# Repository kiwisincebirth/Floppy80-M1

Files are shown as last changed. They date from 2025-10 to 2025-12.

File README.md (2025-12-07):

# Floppy 80 for the TRS-80 Model I

## Features

The Floppy-80 is a Hardware and software solution that emulates 
the following features of the Expansion Interface
- A Floppy Disc controller
  - supports 3 floppy drives
  - single and double-density
  - single and double-sided
  - up to 90 cylinders
  - DMK disk format supported
- 32k RAM expansion (optional)
- 40Hz RTC interrupt generation

Additionally, the following features are provided:
- A Hard Disk Controller (optional)
  - supports up to 2 hard drives
  - Uses same image format as FreHD
- Wait State Generation (optional)
- Software Debugging Interface

An SD card is required to store disk images and configuration data

## Hardware

The Floppy-80 consists of a board that connects to the Model-1 expansion edge connector.
The board contains an SD card socket to provide disk images and a
Raspberry Pi Pico 2 microcontroller which does the emulation

[Building and testing](HARDWARE.md) the board is covered separately.

## Software

The software provided includes 2 main components
* Firmware running on Raspberry Pi, that provides the emulation
* FDC Utility (TRS DOS, and CPM) running on TRS-80 for emulator control

See the separate [Software Build Guide](BUILDING.md) for details on 
building the Floppy-80 software

## User Guide

For User Instructions please see the separate [User Guide](USER-GUIDE.md)

## Credits

## Resources

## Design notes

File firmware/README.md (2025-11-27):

########################################################################

Floppy 80 for the TRS-80 Model I

The Floppy80-M1 emulates the following features of the Expansion Interface
- 32k RAM explansion
- Up to 3 floppy drives
  - 1 and 2 sided
  - single and double density
  - up to 90 cylinders
- Up to 2 hard drives

Configuration of the Floppy80-M1 is performed with the placement of
files on the SD-Card inserted in its card reader.
The files are as follows:

boot.cfg
- specified the defaul ini file to load at reset of the Floppy80
  when the floppy 80 boots or is reset it reads the contents of
  the boot.cfg to determine the default configuration ini file.

ini files
- specifies the disk images and options after reset.

  ini options
  - Drive0 - specified the image to load for drive :0
  - Drive1 - specified the image to load for drive :1
  - Drive2 - specified the image to load for drive :2
  - HD0 - specifies the image to load for tyhe first hard drive
  - HD1 - specifies the image to load for tyhe second hard drive
  - Doubler - 1 = doubler is enabled; 0 = doubler is disabled;

dmk files
- these are virtual disk images with a specific file format
  that allows them to be generated and used with a number
  of existing programs and simulators.

vitual hard drive images
- these are virtual hard drive images with a specific file format.
  They are used by the FreHD and TRS80-GP.

########################################################################

FDC utility
- Is a utility to interact with the Floppy80 from within the
  TRS-80 Model I operating environment.  Versions of FDC exist
  for the following operating systems

  - CPM 1.4.1 (Lifeboat)
  - CPM 1.5 (FMG)
  - Double DOS 4.2.4
  - DOS Plus 3.50
  - LDOS 5.3.1
  - MultiDOS 4.01
  - NEWDOS 3.0
  - NEWDOS 80 V2.0
  - TRSDOS 2.3
  - UltraDOS 4.2.0
  - VTDOS 3.0.0
  - VTDOS 4.0.1

  FDC.COM is used with the two CP/M OSs and
  FDC/CMD is used with the rest.

  Usage

  FDC OPT PARM1:drive

  Where:
  - OPT is one of the following
    - STA - returns the status of the Floppy80.
    - DIR - displays a list of file in the root folder of the SD-Card.
    - INI - switches between tyhe differnt ini file on the SD-Card.
    - DMK - allows the mounting of DMK disk images in the root folder
            of the SD-Card for a specified drive (0, 1 or 2).
    - FOR - copys a DMK disk image from the FOR folder of the SD-Card
            to one of the mounted disk images (0, 1 or 2).
    - IMP - imports a file from the root folder of the SD-Card
            into one of the mounted disk images (0, 1 or 2).

  FDC STA
  - Displays the contects to the ini file specified by boot.cfg

  FDC DIR filter
  - Displays a list of files in the root folder of the SD-Card.
    If filter is specified only files contain the filter character
    sequence are displayed.  If filter is not specified all files
    are displayed.

  FDC INI filename.exe
  - filename.exe is optional.  If not specified and list of ini files
    on the SD-Card will be displayed allow you to select the one to
    write to boot.cfg.  When specified FDC will bypass the file
    selection process.

  FDC DMK filename.exe n
  - filename.exe:n is optional.  When specified it will mount
    the dmk file names by filename.exe into the drive specified
    by n.  For example

    FDC DMK LDOS-DATA.DMK 2

    will mount the dmk file LDOS-DATA.DMK into drive :2

    If filename.exe:n is not specfied a list of dmk files
    will be listed allowing you to select on and the drive
    to mount it into.

  FDC FOR
  - list the files contained in the FMT folder of the SD-Card
    from which you can select one and specify the drive image
    to replace with it.  This is useful to generate blank disk
    images.

  FDC IMP filename.exe:n
  - imports the specified file from the root folder of the
    FAT32 formated SD-Card to the disk image indicated by n.

########################################################################

Building Source
- Floppy80 firmware
  - Uses VSCode and the Pi Pico extension.

- FDC TRS (utility for the TRSDOS related utility)
  
  - zmac fdc.asm
  - use TRS80GP to import FDC/CMD onto a disk image
    
    - trs80gp -m1 -vs -frehd -frehd_dir zout -turbo -mem 48 -d0 dmk\ld531-0.dmk -d1 dmk\ld531-1.dmk -i "IMPORT2 FDC.CMD FDC/CMD:1\r"

- FDC CP/M (utility for the CP/M related utility)
  1. Compile program into a hex file.
  
       zmac fdc.asm
     
  2. Run TRS80GP loading the CP/M disk images.
     
       start trs80gp -m1 -vs -frehd -frehd_dir zout -turbo -mem 48 -d0 CPM141-0.dmk -d1 CPM141-1.dmk -d2 CPM141-2.dmk
     
  3. Select Load from TRS80GP File menu and select the hex file.
  
  4. Run "SAVE 20 B:FDC.COM" to save program memory contents to a .com file.
     As the program grows you will need to increase the value after SAVE.

     SAVE n ufn cr
     
       n   - number of 256-byte pages to be saved.
     
       ufn - unambiguous file name.
     
       cr  - carriage return.

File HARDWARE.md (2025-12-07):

# Floppy 80 (Model I) Hardware

The main components Required are
* Printed Circuit Board
* Raspberry Pi Pico 2 microcontroller
* SN74LVCC4245ADWR Buffer Chips (4x)
* SD Card Socket (SMD)
* 40 pin PCB Edge Connector

## Bill of Materials

For a full Bill Of Materials please see

## Assembly Guide

## Programming Firmware

## Testing

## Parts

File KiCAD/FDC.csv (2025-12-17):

Reference | Qty | Value | Digikey | Cost | Place
C1,C2,C3,C4,C5,C6,C7,C8,C9 | 9 | 100nF | 732-8080-1-ND | 0.10
D1 | 1 | LED | 754-1519-1-ND | 0.70
D2 | 1 | PMEG4010CEJ |  | 0.28 | DNP
J2 | 1 | Conn_02x20_Odd_Even | A31723-ND | 3.69
J3 | 1 | SD_Card | 609-3956-1-ND | 2.13
Q1,Q2 | 2 | SSM3K324RLFCT-ND | SSM3K324RLFCT-ND | 0.37
R1 | 1 | 100 | RMCF0805FT100RCT-ND | 0.10
R2,R3,R4,R6,R8 | 5 | 1k | A106056CT-ND | 0.10
U1,U3,U4,U5 | 4 | SN74LVCC4245ADWR | 296-26634-1-ND | 1.83
U2 | 1 | Pico 2 | 2648-SC1631CT-ND | 5.00

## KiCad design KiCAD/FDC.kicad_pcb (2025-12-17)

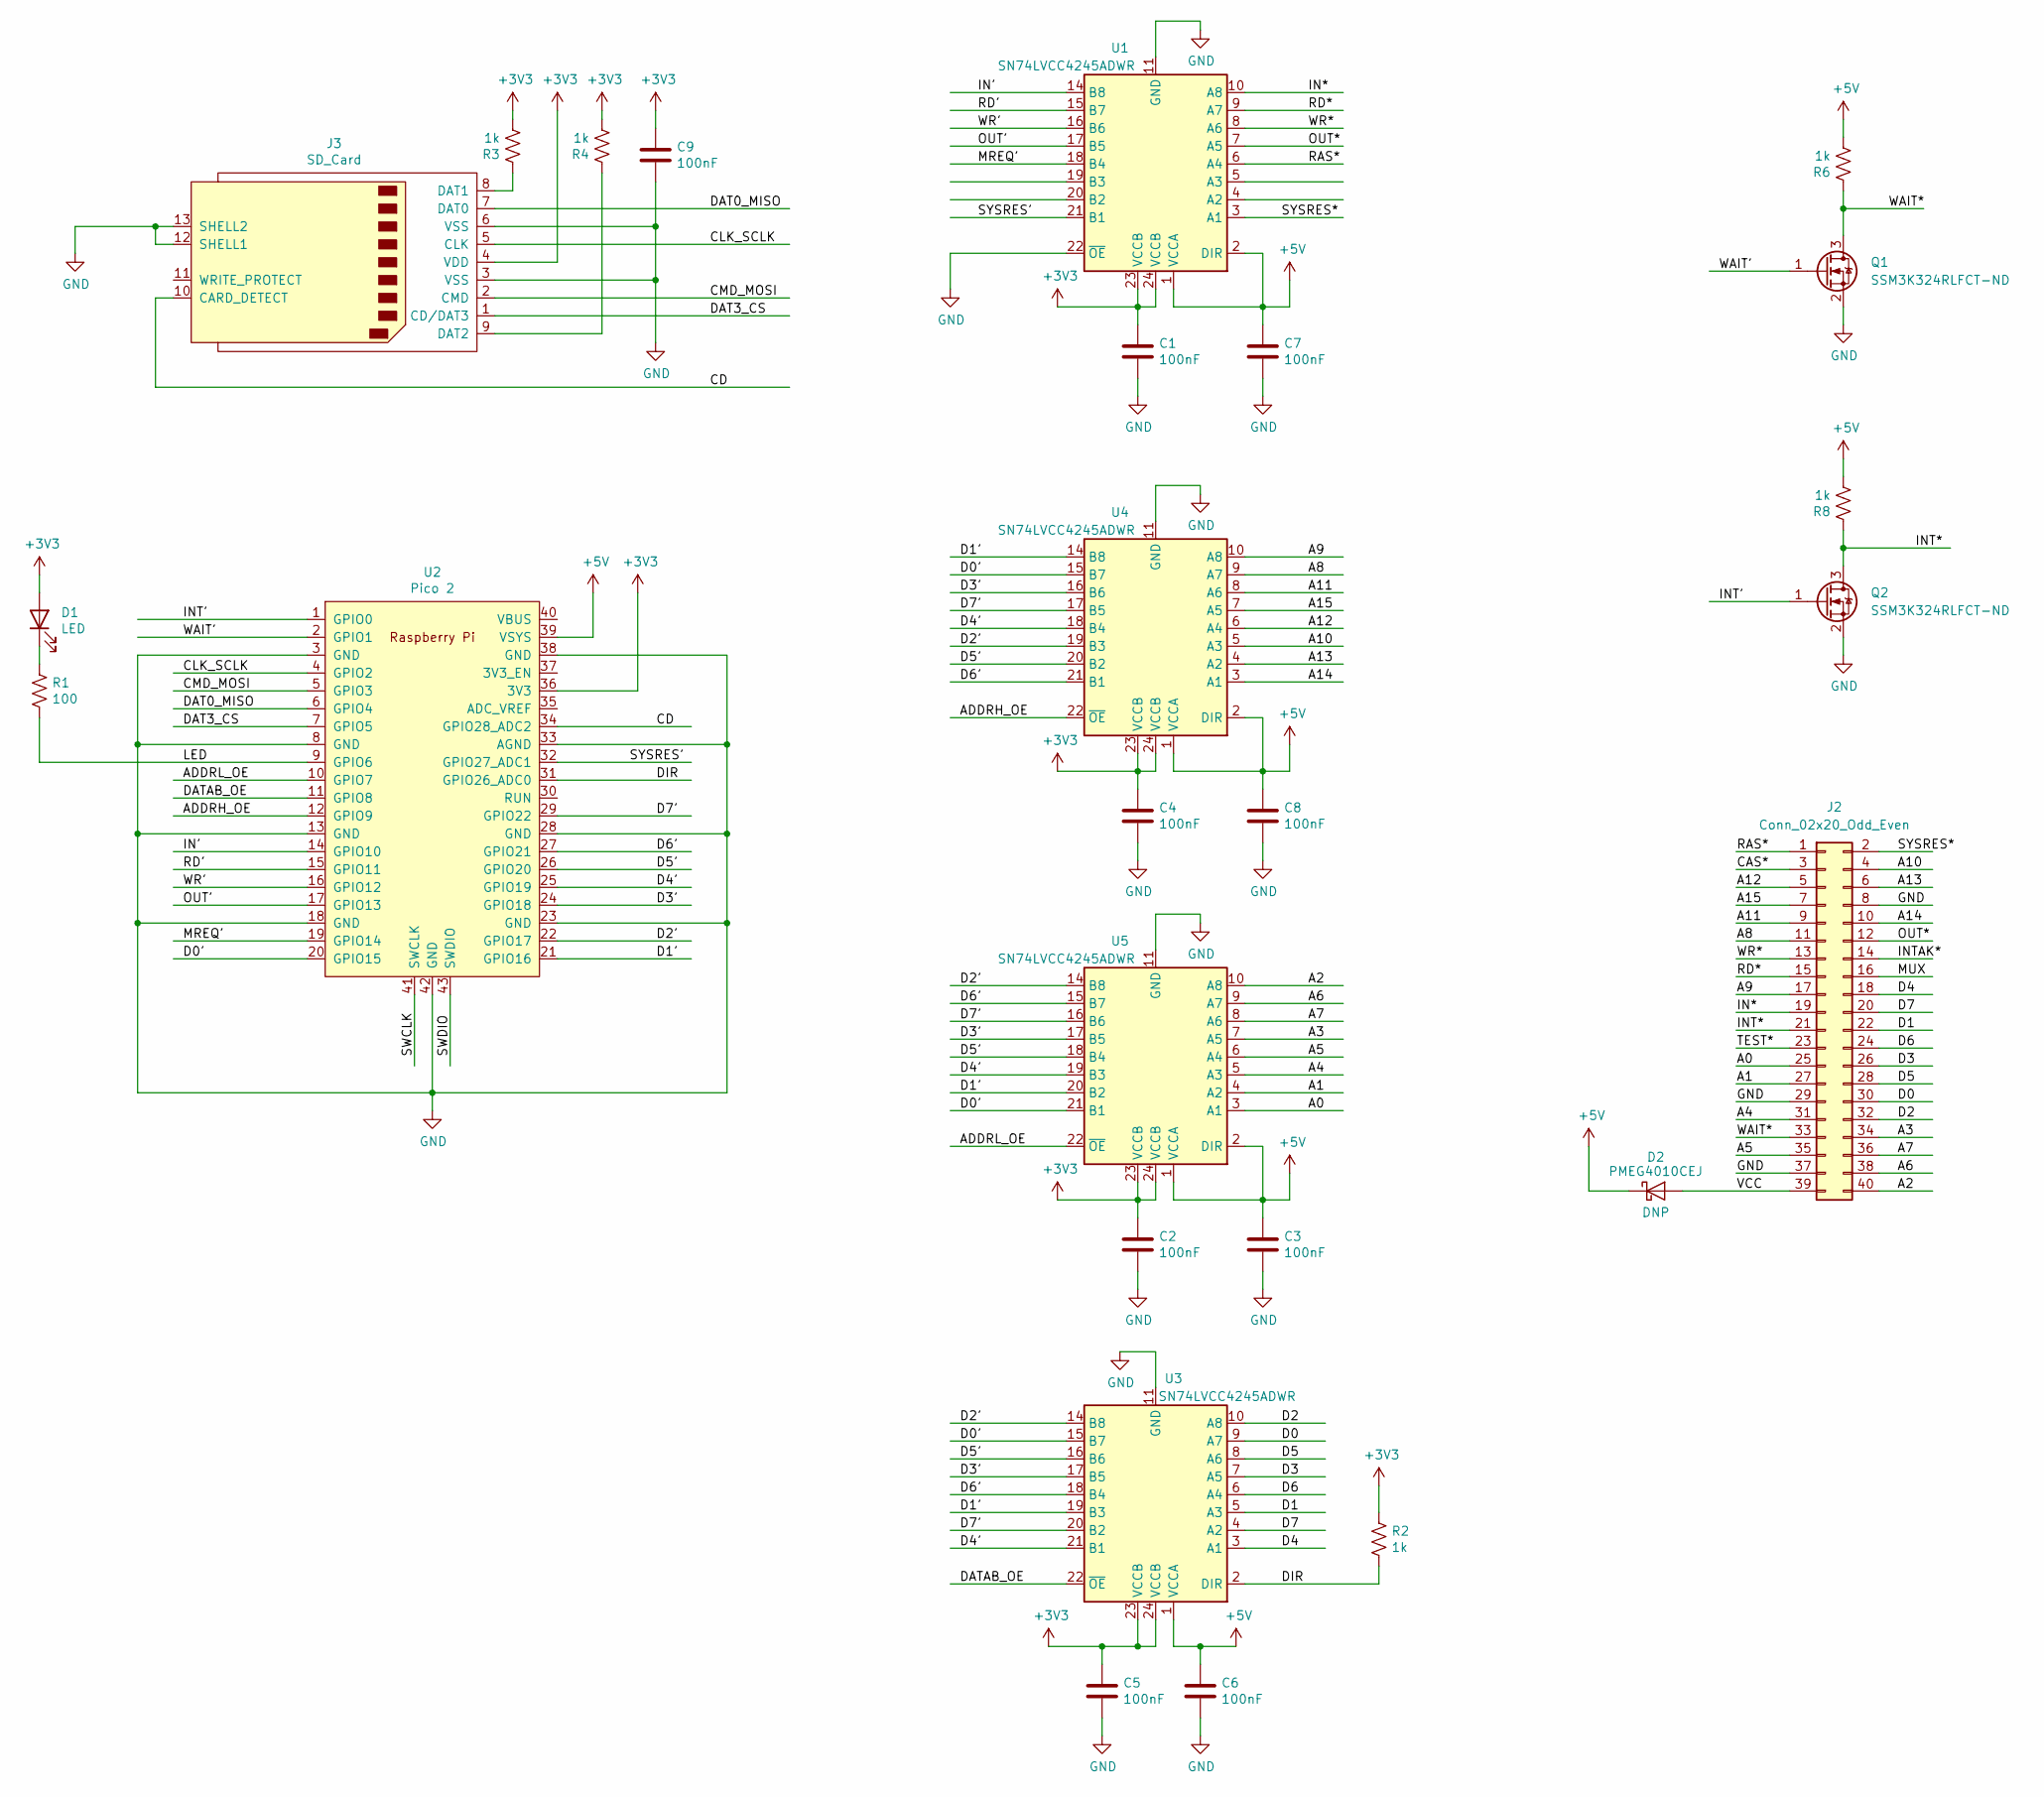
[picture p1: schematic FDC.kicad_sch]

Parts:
C1, C2, C3, C4, C5, C6, C7, C8, C9: 100nF; C_0805_2012Metric_Pad1.18x1.45mm_HandSolder; Digikey 732-8080-1-ND
D1: LED; LED_2816_7142Metric_Pad3.20x4.45mm_HandSolder; Digikey 754-1519-1-ND
D2: PMEG4010CEJ; D_SOD-323F
J2: Conn_02x20_Odd_Even; PinSocket_2x20_P2.54mm_Vertical; Part A31723-ND; Digikey A31723-ND
J3: SD_Card; SD_Kyocera_145638009511859+; Digikey 609-3956-1-ND
Q1, Q2: SSM3K324RLFCT-ND; SOT-23_Handsoldering; Digikey SSM3K324RLFCT-ND
R1: 100; R_0805_2012Metric_Pad1.20x1.40mm_HandSolder; Digikey RMCF0805FT100RCT-ND
R2, R3, R4, R6, R8: 1k; R_0805_2012Metric_Pad1.20x1.40mm_HandSolder; Digikey A106056CT-ND
U1, U3, U4, U5: SN74LVCC4245ADWR; SOIC-24W_7.5x15.4mm_P1.27mm; Digikey 296-26634-1-ND
U2: Pico 2; RPi_Pico_SMD_TH; Digikey 2648-SC1631CT-ND

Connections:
+3V3: C1.1, C2.1, C4.1, C5.1, C9.1, D1.2 (A), J3.4 (VDD), R2.1, R3.2, R4.2, U1.23 (VCCB), U1.24 (VCCB), U2.36 (3V3), U3.23 (VCCB), U3.24 (VCCB), U4.23 (VCCB), U4.24 (VCCB), U5.23 (VCCB), U5.24 (VCCB)
+5V: C3.1, C6.1, C7.1, C8.1, D2.1 (K), R6.2, R8.2, U1.1 (VCCA), U1.2 (DIR), U2.39 (VSYS), U3.1 (VCCA), U4.1 (VCCA), U4.2 (DIR), U5.1 (VCCA), U5.2 (DIR)
/A0: J2.25, U5.3 (A1)
/A1: J2.27, U5.4 (A2)
/A2: J2.40, U5.10 (A8)
/A3: J2.34, U5.7 (A5)
/A4: J2.31, U5.5 (A3)
/A5: J2.35, U5.6 (A4)
/A6: J2.38, U5.9 (A7)
/A7: J2.36, U5.8 (A6)
/A8: J2.11, U4.9 (A7)
/A9: J2.17, U4.10 (A8)
/A10: J2.4, U4.5 (A3)
/A11: J2.9, U4.8 (A6)
/A12: J2.5, U4.6 (A4)
/A13: J2.6, U4.4 (A2)
/A14: J2.10, U4.3 (A1)
/A15: J2.7, U4.7 (A5)
/ADDRH_OE: U2.12 (GPIO9), U4.22 (~OE)
/ADDRL_OE: U2.10 (GPIO7), U5.22 (~OE)
/CAS*: J2.3
/CD: J3.10 (CARD_DETECT), U2.34 (GPIO28_ADC2)
/CLK_SCLK: J3.5 (CLK), U2.4 (GPIO2)
/CMD_MOSI: J3.2 (CMD), U2.5 (GPIO3)
/D0: J2.30, U3.9 (A7)
/D0': U2.20 (GPIO15), U3.15 (B7), U4.15 (B7), U5.21 (B1)
/D1: J2.22, U3.5 (A3)
/D1': U2.21 (GPIO16), U3.19 (B3), U4.14 (B8), U5.20 (B2)
/D2: J2.32, U3.10 (A8)
/D2': U2.22 (GPIO17), U3.14 (B8), U4.19 (B3), U5.14 (B8)
/D3: J2.26, U3.7 (A5)
/D3': U2.24 (GPIO18), U3.17 (B5), U4.16 (B6), U5.17 (B5)
/D4: J2.18, U3.3 (A1)
/D4': U2.25 (GPIO19), U3.21 (B1), U4.18 (B4), U5.19 (B3)
/D5: J2.28, U3.8 (A6)
/D5': U2.26 (GPIO20), U3.16 (B6), U4.20 (B2), U5.18 (B4)
/D6: J2.24, U3.6 (A4)
/D6': U2.27 (GPIO21), U3.18 (B4), U4.21 (B1), U5.15 (B7)
/D7: J2.20, U3.4 (A2)
/D7': U2.29 (GPIO22), U3.20 (B2), U4.17 (B5), U5.16 (B6)
/DAT0_MISO: J3.7 (DAT0), U2.6 (GPIO4)
/DAT3_CS: J3.1 (CD/DAT3), U2.7 (GPIO5)
/DATAB_OE: U2.11 (GPIO8), U3.22 (~OE)
/DIR: R2.2, U2.31 (GPIO26_ADC0), U3.2 (DIR)
/IN': U1.14 (B8), U2.14 (GPIO10)
/IN*: J2.19, U1.10 (A8)
/INT': Q2.1 (G), U2.1 (GPIO0)
/INT*: J2.21, Q2.3 (D), R8.1
/INTAK*: J2.14
/LED: R1.2, U2.9 (GPIO6)
/MREQ': U1.18 (B4), U2.19 (GPIO14)
/MUX: J2.16
/OUT': U1.17 (B5), U2.17 (GPIO13)
/OUT*: J2.12, U1.7 (A5)
/RAS*: J2.1, U1.6 (A4)
/RD': U1.15 (B7), U2.15 (GPIO11)
/RD*: J2.15, U1.9 (A7)
/SWCLK: U2.41 (SWCLK)
/SWDIO: U2.43 (SWDIO)
/SYSRES': U1.21 (B1), U2.32 (GPIO27_ADC1)
/SYSRES*: J2.2, U1.3 (A1)
/TEST*: J2.23
/VCC: D2.2 (A), J2.39
/WAIT': Q1.1 (G), U2.2 (GPIO1)
/WAIT*: J2.33, Q1.3 (D), R6.1
/WR': U1.16 (B6), U2.16 (GPIO12)
/WR*: J2.13, U1.8 (A6)
GND: C1.2, C2.2, C3.2, C4.2, C5.2, C6.2, C7.2, C8.2, C9.2, J2.8, J2.29, J2.37, J3.3 (VSS), J3.6 (VSS), J3.12 (SHELL1), J3.13 (SHELL2), Q1.2 (S), Q2.2 (S), U1.11 (GND), U1.12 (GND), U1.13 (GND), U1.22 (~OE), U2.3 (GND), U2.8 (GND), U2.13 (GND), U2.18 (GND), U2.23 (GND), U2.28 (GND), U2.33 (AGND), U2.38 (GND), U2.42 (GND), U3.11 (GND), U3.12 (GND), U3.13 (GND), U4.11 (GND), U4.12 (GND), U4.13 (GND), U5.11 (GND), U5.12 (GND), U5.13 (GND)
unnamed: D1.1 (K), R1.1
unnamed: J3.8 (DAT1), R3.1
unnamed: J3.9 (DAT2), R4.1

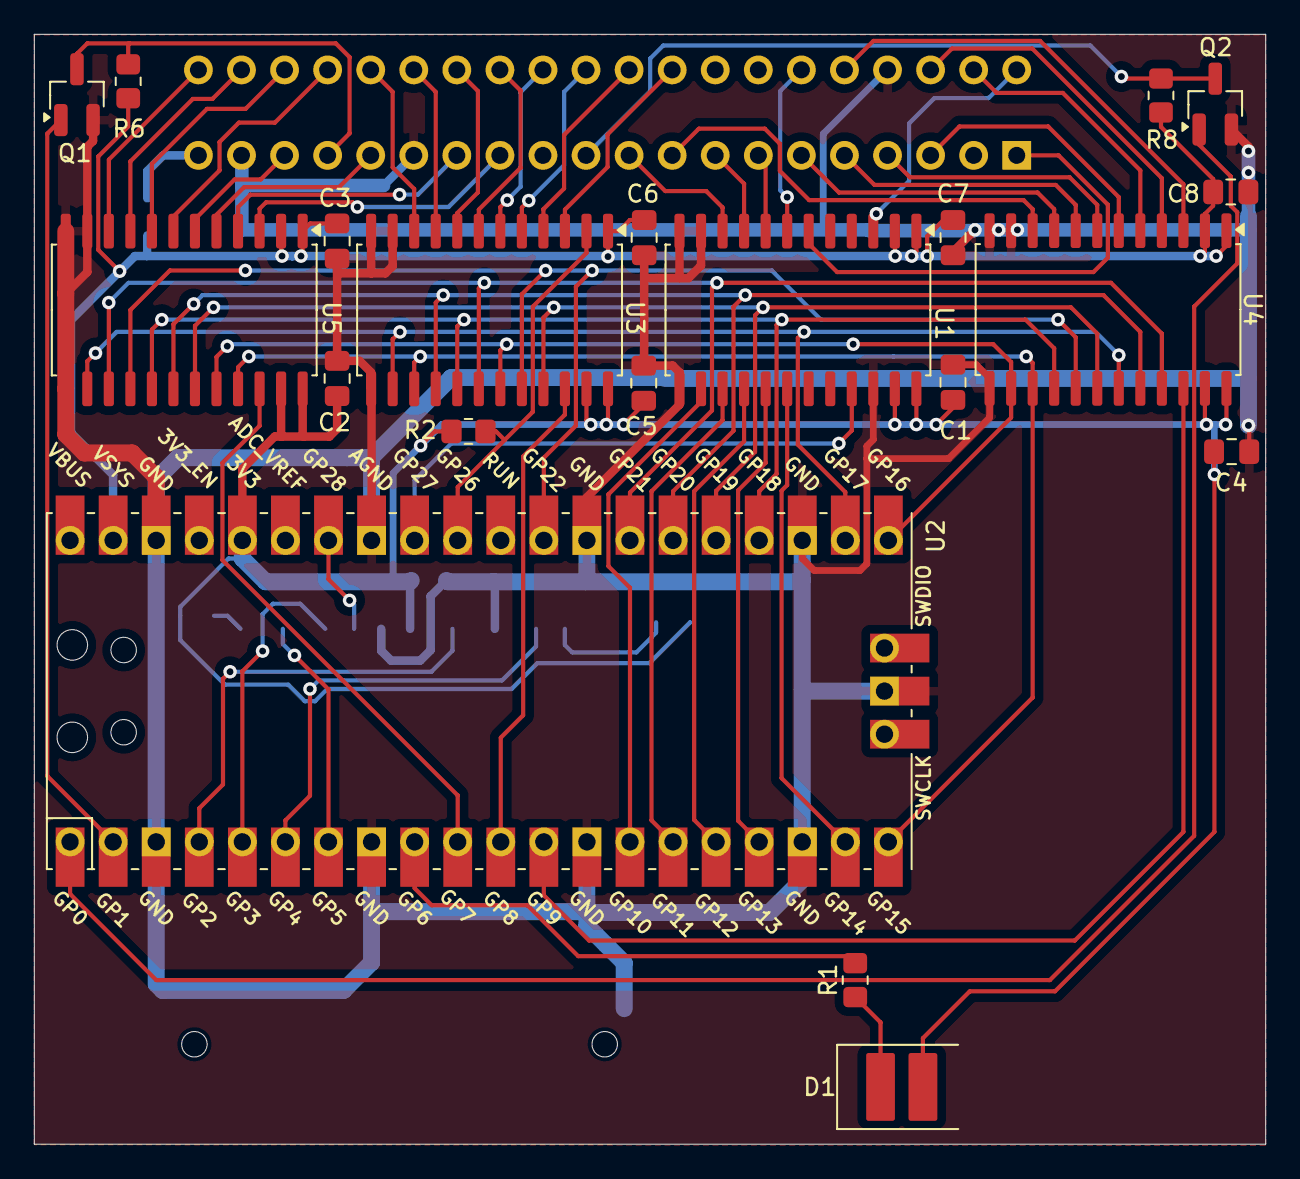
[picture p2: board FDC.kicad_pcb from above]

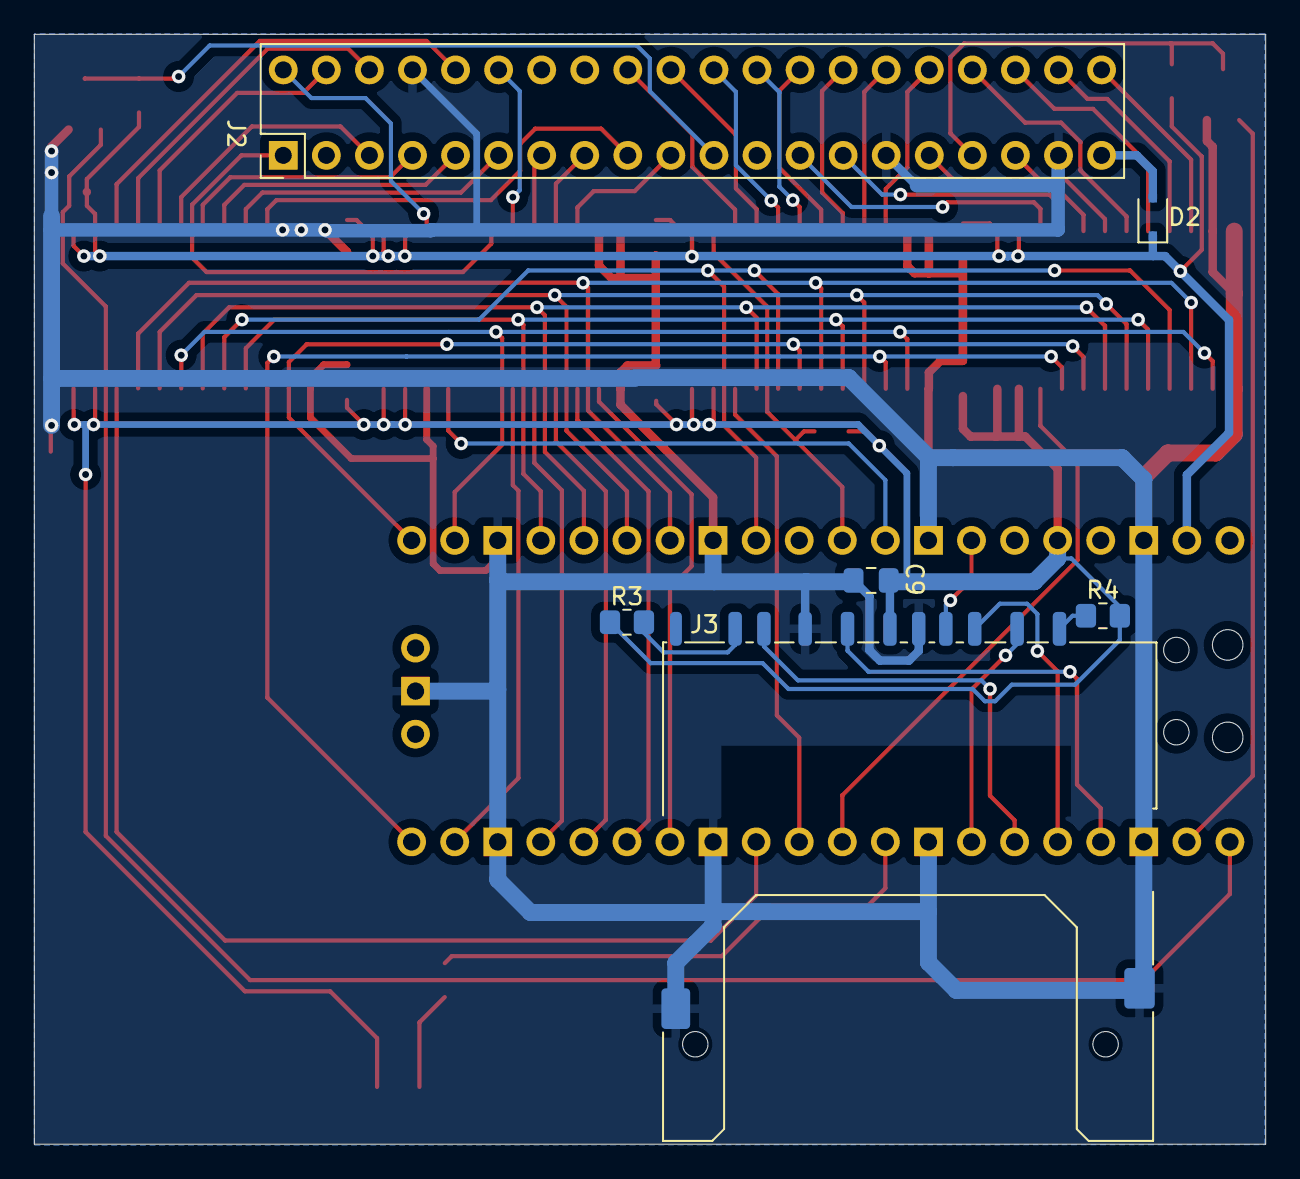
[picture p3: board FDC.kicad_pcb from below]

Board: 2 copper layers, 72.6 x 65.5 mm, 26 parts (6 on the bottom side), 65 nets.

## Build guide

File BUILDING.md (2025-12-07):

# Floppy 80 (Model I) Software Build

## Floppy80 firmware

You need to install the C SDK for RPI
https://www.raspberrypi.com/documentation/microcontrollers/c_sdk.html#sdk-setup

CMake and Make are essential for this to work
* On Mac OSX - `brew install cmake`

```
# ensure you are in the firmware directory
cd firmware

# first run cmake - creating a separate build folder 
cmake -B build -S .

# then from the build folder
cd build

# run the make command
make Floppy80
```

this will create Floppy80.uf2 file which you burn to the RPI PICO

Alternately you can use VSCode and the RPI Pico extension.

### Background Reading

These are DEV resources:
* https://www.raspberrypi.com/documentation/microcontrollers/c_sdk.html
* https://admantium.medium.com/getting-started-with-raspberry-pico-and-cmake-f536e18512e6

## FDC (for TRSDOS)

FDC TRS (utility for the TRSDOS related utility)

```
cd FDC\ TRS`
zmac fdc.asm
```

use TRS80GP to import FDC/CMD onto a disk image

```
trs80gp -m1 -vs -frehd -frehd_dir zout -turbo -mem 48 -d0 dmk\ld531-0.dmk -d1 dmk\ld531-1.dmk -i "IMPORT2 FDC.CMD FDC/CMD:1\r"
```

## FDC (for CP/M)

FDC CP/M (utility for the CP/M related utility)

Compile program into a hex file.

```
cd FDC\ CPM`
zmac fdc.asm
```

Run TRS80GP loading the CP/M disk images.

```
trs80gp -m1 -vs -frehd -frehd_dir zout -turbo -mem 48 -d0 CPM141-0.dmk -d1 CPM141-1.dmk -d2 CPM141-2.dmk
```

Select Load from TRS80GP File menu and select the hex file.

Run the SAVE command to save program memory contents to a .COM file.
As the program grows you will need to increase the value after SAVE.
i.e. `SAVE n ufn` Where :
* n   - number of 256-byte pages to be saved.
* ufn - unambiguous file name.

e.g.

`SAVE 20 B:FDC.COM`

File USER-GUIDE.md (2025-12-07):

# Floppy 80 (Model I) User Guide

## Configuration

An SD Card (FAT formatted), is required to contain the disk images, and configuration

Configuration of the Floppy80-M1 is performed with the placement of
files on the SD-Card inserted in its card reader. 
Files are placed in the Root folder (unless noted), sub folders are 
not generally supported. The files are as follows:

### system.cfg

This file contains global configuraton settings. The file and settings are
optional and all have meaninful defaults The settings are:
* MEM - Used to enable / disable 32KB RAM; 1 = enabled (default); 0 = disabled
* WAIT - Used to enable / disable wait states 1 = enabled; 0 = disabled (default)

e.g.
```
MEM=1
WAIT=0
```

Wait states are used to slow the Z80 CPU, to get it to wait for all
floppy disk controller actions to complete before continuing.
Typically, wait states should not be required.

Wait states are useful for overclocked CPU's where the CPU outperforms
the Floppy emulation, which is optimised for normal CPU speed.
The issue with wait states it they are known to disrupt
critical timed operations, such as formatting a floppy disk.

### boot.cfg
Specify the default INI file to load at reset of the Floppy80
when the floppy 80 boots or is reset it reads the contents of
the boot.cfg to determine the default configuration INI file.

This file contains (ONLY) the name of the current INI file being used e.g.

e.g.
```
LD531.INI
```

### INI files
Specifies the disk images and options after reset. Options 
* Drive0 - specified the image to load for drive :0
* Drive1 - specified the image to load for drive :1
* Drive2 - specified the image to load for drive :2
* HD0 - specifies the image to load for the first hard drive
* HD1 - specifies the image to load for the second hard drive
* Doubler - 1 = doubler is enabled; 0 = doubler is disabled;

e.g.
``` 
Drive0=LD531-0.dmk
Drive1=LD531-1.dmk
Drive2=LD531-2.dmk
HD0=hard0.hdv
Doubler=1
```

### DMK files
Virtual floppy disk images with a specific file format
that allows them to be generated and used with a number
of existing programs and simulators.

### Virtual Hard Drive Images
Virtual hard drive images with a specific file format.
They are the same format as is used by the FreHD and TRS80-GP.

### /FMT folder
A folder which can contain blank floppy images, these are not mountable.
Instead, they used by the `FDC FMT` command. See [FDC FOR](#fdc-for) section below

## Operation

The Floppy80 should be powered on before the Main computer is powered.
Power is provided by the USB port on the Pi Pico microcontroller.

The Floppy-80 has an LED which shows disk activity.

### Startup

When Floppy80 first starts it uses `boot.cfg` to load the default 
disk images.

### FDC Utility

Is a utility to interact with the Floppy80 from within the
TRS-80 Model I operating environment.  Versions of FDC exist
for both the CPM (Lifeboard and FMG) and most TRS DOS based operating Systems.

#### FDC STA

Displays a status, and the contents to the INI file specified by boot.cfg

#### FDC DIR [fiter]

Displays a list of files in the root folder of the SD-Card.
If filter is specified only files containing the filter character sequence are displayed.  
If filter is not specified all files are displayed.

#### FDC INI [filename.ini]

Switches between the different INI file on the SD-Card. 
If filename.ini is not specified a list of INI files on the SD-Card will be displayed 
and you can select the one to write to boot.cfg

#### FDC DMK [filename.dmk] [0/1/2]

Allows the mounting of DMK disk images in the root folder of the SD-Card for a specified drive.
When filename.dmk is specified it will mount the DMK file names by filename.dmk into the drive specified
[0/1/2].  For example

`FDC DMK LDOS-DATA.DMK 2` will mount the DMK file LDOS-DATA.DMK into drive :2
`FDC DMK` - will list DMK files allowing you to select the file, and the drive to mount it into

#### FDC FOR

Format a Floppy Disk - Copies a DMK disk image from the `/FMT` folder of the SD-Card 
to one of the mounted disk images (0, 1 or 2)

List the files contained in the `/FMT` folder of the SD-Card from which you can select one 
and specify the drive image to replace with it.

This utility is a backup if the native format function does not work.

#### FDC IMP [filename.ext] :n

imports the specified file from the root folder of the FAT32 formatted SD-Card to the disk image indicated by n.
imports a file from the root folder of the SD-Card into one of the mounted disk images (0, 1 or 2).

## Operating Systems

### CPM 1.4.1 (Lifeboat)

Format works.

### CPM 1.5 (FGM)

Format works.

### Double DOS 4.2.4

Format works.

### DOS Plus 3.50

Format works, provided you start with a double sides dmk file.

Backup works as long as disk doubler is disabled

### LDOS 5.3.1

Format works, supports only single density at this time, and requires a reboot after formatting drive.

### MultiDOS 4.01

Format works.

Backup works, as long as disk doublers are disabled.

### NEWDOS 3.0

Format works.

### NEWDOS 80 V2.0

Format works.

### TRSDOS 2.3

Format works.

### UltraDOS 4.2.0

Format works.

### VTDOS 3.0.0

Format works.

BACKUP - Different Pack IDs

## VTDOS 4.0.1

Format works.

Backup works, as long as disk doublers are disabled.

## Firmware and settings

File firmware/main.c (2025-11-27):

#include <stdio.h>
#include <string.h>
#include "pico/stdlib.h"
#include "pico/multicore.h"
#include "hardware/gpio.h"

#include "hardware/pio.h"
#include "hardware/irq.h"
#include "hardware/regs/intctrl.h"
#include "hardware/clocks.h"
#include "hardware/structs/systick.h"

#include "defines.h"
#include "sd_core.h"
#include "fdc.h"
#include "hdc.h"
#include "system.h"
#include "cli.h"
#include "memory.h"

///////////////////////////////////////////////////////////////////////////////
// API documentions is located at
// https://raspberrypi.github.io/pico-sdk-doxygen/
///////////////////////////////////////////////////////////////////////////////

///////////////////////////////////////////////////////////////////////////////
// to get memory usage of the compilied program enter
//
//   size build/Floppy80.elf
//
// in a bash terminal window
//
// Output is
// - text gives you the size of the text segment (or code segment).
// - data gives you the size of the data segment.
// - bss gives you the size of the block started by symbol segment.
// - dec is the size of the text, data and bss size added together in decimal, and hex is the same number in hexadecimal.
///////////////////////////////////////////////////////////////////////////////

///////////////////////////////////////////////////////////////////////////////
// GPIO NET        IN   OUT
//-----------------------------------------------------------------------------
// 0	INT         	 * (drives a transistor to pull the Z80 Interrupt line low)
// 1    WAIT             * (drives a transistor to pull the Z80 Wait line low)
// 2    CLK_SCLK         * (SD-Card)
// 3    CMD_MOSI         * (SD-Card)
//
// 4    DAT0_MISO   *      (SD-Card)
// 5    DAT3_CS          * (SD-Card)
// 6    CD               * (SD-Card, Card Detect)
// 7    ADDRL_OE         * (Enable the low (A0-A7) byte address buffer for reading)
//
// 8    DATAB_OE         * (Enable the data bus for reading)
// 9    IN          *      (Z80 bus for port I/O, input)
// 10   ADDRH_OE         * (Enable the high (A8-A15) byte address buffer for reading)
// 11   RD          *      (Z80 bus for memory read)
//
// 12   WR          *      (Z80 bus for memory write)
// 13   OUT         *      (Z80 bus for port I/O, output)
// 14   LED              * (active low enable for the activity LED)
// 15   INT              * (drives a transistor to pull the Z80 interrupt line low)
//
// 16   D0          *    * (bit 0 of the data bus to read A0-A7, A8-A15 and D0-D7, and wite D0-D7)
// 17   D1          *    * (bit 1 of the data bus)
// 18   D2          *    * (bit 2 of the data bus)
// 19   D3          *    * (bit 3 of the data bus)
//
// 20   D4          *    * (bit 4 of the data bus)
// 21   D5          *    * (bit 5 of the data bus)
// 22   D6          *    * (bit 6 of the data bus)
// 23   NA
//
// 24   NA
// 25   NA
// 26   D7          *    * (bit 7 of the data bus)
// 27   DIR              * (controls the direction of the data bus buffer)
//
// 28   SYSRES      *      (Z80 bus reset state)
// 29	-
// 30	-
// 31	-
//
//-----------------------------------------------------------------------------
void InitGPIO(void)
{
    gpio_init(INT_PIN);
    gpio_set_dir(INT_PIN, GPIO_OUT);
    gpio_set_slew_rate(INT_PIN, GPIO_SLEW_RATE_FAST);
    gpio_set_drive_strength(INT_PIN, GPIO_DRIVE_STRENGTH_2MA);
    gpio_put(INT_PIN, 0); // deactivate intr

    gpio_init(WAIT_PIN);
    gpio_set_dir(WAIT_PIN, GPIO_OUT);
    gpio_set_slew_rate(WAIT_PIN, GPIO_SLEW_RATE_FAST);
    gpio_set_drive_strength(WAIT_PIN, GPIO_DRIVE_STRENGTH_2MA);
    gpio_put(WAIT_PIN, 0); // deactivate wait

    // CLK_SCLK - initailized by the SD-Card library
    // CMD_MOSI
    // DAT0_MISO
    // DAT3_CS

    gpio_init(LED_PIN);
    gpio_set_dir(LED_PIN, GPIO_OUT);
    gpio_set_slew_rate(LED_PIN, GPIO_SLEW_RATE_SLOW);
    gpio_set_drive_strength(LED_PIN, GPIO_DRIVE_STRENGTH_2MA);
    gpio_put(LED_PIN, 1); // LED off

    gpio_init(ADDRL_OE_PIN);
    gpio_set_dir(ADDRL_OE_PIN, GPIO_OUT);
    gpio_set_slew_rate(ADDRL_OE_PIN, GPIO_SLEW_RATE_FAST);
    gpio_set_drive_strength(ADDRL_OE_PIN, GPIO_DRIVE_STRENGTH_12MA);
    gpio_put(ADDRL_OE_PIN, 1); // deactivate low address bus input buffer

    gpio_init(DATAB_OE_PIN);
    gpio_set_dir(DATAB_OE_PIN, GPIO_OUT);
    gpio_set_slew_rate(DATAB_OE_PIN, GPIO_SLEW_RATE_FAST);
    gpio_set_drive_strength(DATAB_OE_PIN, GPIO_DRIVE_STRENGTH_12MA);
    gpio_put(DATAB_OE_PIN, 1); // deactivate data bus I/O buffer

    gpio_init(ADDRH_OE_PIN);
    gpio_set_dir(ADDRH_OE_PIN, GPIO_OUT);
    gpio_set_slew_rate(ADDRH_OE_PIN, GPIO_SLEW_RATE_FAST);
    gpio_set_drive_strength(ADDRH_OE_PIN, GPIO_DRIVE_STRENGTH_12MA);
    gpio_put(ADDRH_OE_PIN, 1); // deactivate high address bus input buffer

    gpio_init(IN_PIN);
    gpio_set_dir(IN_PIN, GPIO_IN);

    gpio_init(RD_PIN);
    gpio_set_dir(RD_PIN, GPIO_IN);

    gpio_init(WR_PIN);
    gpio_set_dir(WR_PIN, GPIO_IN);

    gpio_init(OUT_PIN);
    gpio_set_dir(OUT_PIN, GPIO_IN);

    gpio_init(MREQ_PIN);
    gpio_set_dir(MREQ_PIN, GPIO_IN);

    gpio_init(D0_PIN);
    gpio_set_dir(D0_PIN, GPIO_IN);

    gpio_init(D1_PIN);
    gpio_set_dir(D1_PIN, GPIO_IN);

    gpio_init(D2_PIN);
    gpio_set_dir(D2_PIN, GPIO_IN);

    gpio_init(D3_PIN);
    gpio_set_dir(D3_PIN, GPIO_IN);

    gpio_init(D4_PIN);
    gpio_set_dir(D4_PIN, GPIO_IN);

    gpio_init(D5_PIN);
    gpio_set_dir(D5_PIN, GPIO_IN);

    gpio_init(D6_PIN);
    gpio_set_dir(D6_PIN, GPIO_IN);

    gpio_init(D7_PIN);
    gpio_set_dir(D7_PIN, GPIO_IN);

    gpio_init(DIR_PIN);
    gpio_set_dir(DIR_PIN, GPIO_OUT);
    gpio_set_slew_rate(DIR_PIN, GPIO_SLEW_RATE_FAST);
    gpio_put(DIR_PIN, A_TO_B_DIR); // A to B direction

    gpio_init(SYSRES_PIN);
    gpio_set_dir(SYSRES_PIN, GPIO_IN);

    gpio_init(CD_PIN);
    gpio_set_dir(CD_PIN, GPIO_IN);
    gpio_set_pulls(CD_PIN, true, false);
}

///////////////////////////////////////////////////////////////////////////////
int main()
{
    stdio_init_all();

    InitGPIO();
    InitVars();
    SDHC_Init();
    FileSystemInit();
    FdcInit();
    HdcInit();
    InitCli();

    multicore_launch_core1(service_memory);

    // wait for reset to be released
    while (g_byResetActive)
    {
        // tight_loop_contents();
        ServiceCli();
    }

    while (true)
    {
        UpdateCounters();
        FdcServiceStateMachine();
        HdcServiceStateMachine();
        ServiceCli();
    }
}

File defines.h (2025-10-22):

#ifndef _H_DEFINES_
#define _H_DEFINES_

#define ENABLE_DOUBLER 1
#define ENABLE_LOGGING 1

//#pragma GCC optimize ("O0")
#pragma GCC optimize ("O3")

#include <stdio.h>

#define CDC_ITF     0           /* USB CDC interface no */

typedef signed char        	int8_t;
typedef unsigned char		uint8_t;
typedef short              	int16_t;
typedef unsigned short     	uint16_t;
typedef long               	int32_t;
typedef unsigned long      	uint32_t;
typedef long long          	int64_t;
typedef unsigned long long 	uint64_t;

typedef unsigned char		byte;
typedef unsigned short     	word;
typedef unsigned long      	dword;

#define SizeOfArray(x) (sizeof(x) / sizeof(x[0]))

// set to 1 to enable capture of bus activity logging to sd-card
#define ENABLE_TRACE_LOG 0

#define INT_PIN       0
#define WAIT_PIN      1
#define CLK_SCLK      2
#define CMD_MOSI      3

#define DAT0_MISO     4
#define DAT3_CS       5
#define LED_PIN       6
#define ADDRL_OE_PIN  7

#define DATAB_OE_PIN  8
#define ADDRH_OE_PIN  9
#define IN_PIN        10
#define RD_PIN        11

#define WR_PIN        12
#define OUT_PIN       13
#define MREQ_PIN      14
#define D0_PIN        15

#define D1_PIN        16
#define D2_PIN        17
#define D3_PIN        18
#define D4_PIN        19

#define D5_PIN        20
#define D6_PIN        21
#define D7_PIN        22

#define DIR_PIN       26
#define SYSRES_PIN    27
#define CD_PIN        28

// Bit  Net      Input    Hex
//             (1=input)
// 31    -         0
// 30    -         0
// 29    -         0
// 28    CD        1       1     0
//
// 27    SYSRES    1
// 26    DIR       0
// 25    -         0
// 24    -         0       8     0
//
// 23    -         0
// 22    D7        1
// 21    D6        1
// 20    D5        1       7     7
//
// 19    D4        1
// 18    D3        1
// 17    D2        1
// 16    D1        1       F     F
//
// 15    D0        1
// 14    RAS       1
// 13    OUT       1
// 12    WR        1       F     8
//
// 11    RD        1
// 10    IN        1
//  9    ADDRH     0
//  8    DATAB     0       C     0
//
//  7    ADDRL     0
//  6    LED       0
//  5    DAT3_CS   0
//  4    DAT0_MISO 0       0     0
//
//  3    CMD_MOSI  0
//  2    CLK_SCLK  0
//  1    WAIT      0
//  0    INT       0       0     0

#define GPIO_IN_MASK  0x187FFC00
#define DATA_BUS_MASK 0x007F8000

#define A_TO_B_DIR 1
#define B_TO_A_DIR 0

///////////////////////////////////////////////////////////////////////////////////////////////////

#define get_gpio_data_byte() (sio_hw->gpio_in >> D0_PIN)
#define get_gpio_read_bus()  (sio_hw->gpio_in >> IN_PIN)
#define get_gpio(gpio)       (sio_hw->gpio_in & (1u << gpio))
#define set_gpio(gpio)        sio_hw->gpio_set = 1u << gpio
#define clr_gpio(gpio)        sio_hw->gpio_clr = 1u << gpio
#define set_bus_as_output()   sio_hw->gpio_oe_set = 0xFF << D0_PIN
#define set_bus_as_input()    sio_hw->gpio_oe_clr = 0xFF << D0_PIN
#define put_byte_on_bus(data) sio_hw->gpio_togl = (sio_hw->gpio_out ^ (data << D0_PIN)) & (0xFF << D0_PIN)

// #define get_gpio_data_byte()  gpio_get_all() >> D0_PIN
// #define get_gpio(gpio)        gpio_get(gpio)
// #define set_gpio(gpio)        gpio_put(gpio, 1)
// #define clr_gpio(gpio)        gpio_put(gpio, 0)
// #define set_bus_as_output()   gpio_set_dir_out_masked(0xFF << D0_PIN)
// #define set_bus_as_input()    gpio_set_dir_in_masked(0xFF << D0_PIN)
// #define put_byte_on_bus(data) gpio_put_masked(0xFF << D0_PIN, data << D0_PIN)

///////////////////////////////////////////////////////////////////////////////////////////////////

// Low Power Timer Overflow Rates in Hz
#define TIMER_OVERFLOW_RATE 2000

///////////////////////////////////////////////////////////////////////////////////////////////////
// generic defines/equates

#ifndef TRUE
	#define FALSE	0
	#define TRUE	1
#endif

#ifndef true
	#define false	0
	#define true	1
#endif

#ifndef MAX_PATH
  #define MAX_PATH 64
#endif

///////////////////////////////////////////////////////////////////////////////////////////////////
// FDC logging

typedef struct {
	uint8_t type;
	uint8_t val;
	uint8_t op1;
	uint8_t op2;
} LogType;

#define LOG_SIZE 4096

extern LogType fdc_log[LOG_SIZE];
extern int log_head;
extern int log_tail;

enum {
	write_drive_select = 0,
	write_data,
	write_sector,
	write_track,
	write_cmd,
	read_drive_select,
	read_data,
	read_sector,
	read_track,
	read_status,
	port_out,
	port_in
};

///////////////////////////////////////////////////////////////////////////////////////////////////
// typedefs

typedef struct {
   uint64_t nSectorsTotal;
   uint64_t nSectorsFree;
   uint64_t nSectorSize;

   uint32_t nClustersTotal;
   uint32_t nClustersFree;
   uint32_t nClustersUsed;
   uint32_t nClustersBad;
   uint32_t nClusterSize;
} F_SPACE;

///////////////////////////////////////////////////////////////////////////////////////////////////
// enumerations

enum {
  opRead = 0,
  opWrite,
  opNop
};
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

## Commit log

2024-10-13 Reduced SPI clock to 5MHz for more reliability.
2024-10-15 Implements mount request/response
2024-10-25 Switched to pico 2
2024-10-27 Supports easier switch from pico to pico 2.
2024-11-01 Corrects CRC write to disk error. Allows formatting of drives under CP/M.
    [fdc.c, fdc.h, memory.c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]
2024-11-03 Activates WAIT for all memory operations. Sacrifices speed for stability.
    [fdc.c, fdc.h, memory.c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]
2024-11-03 Adding hardware design to the repository.
    [FDC.kicad_pcb, FDC.kicad_sch]
2024-11-03 Changes for stability, don't know why they make it more stable yet.
    [fdc.h, memory.c, system.c]
2024-12-22 Replaces disassembled instructions as data statements.
    [FORMAT.ASM]
2025-09-22 Resets system after reset line is low for > 1ms
    [system.c]
2025-09-24 Switches to the watchdog for a system reset
    [system.c]
2025-09-27 Enable CLI while waiting for release of reset line.
    [main.c]
2025-09-27 Corrects an error is setting the DRQ status bit
    [fdc.c]
2025-10-16 Corrected issue were INTR output needs to be disabled after RD line goes inactive.
    [defines.h, fdc.c, memory.c]
2025-10-20 Improves timing to resolve backup/cmd issue while still supporting HDC emulation.
    [memory.c]
2025-12-09 Filtering of hidden files
2025-12-17 Updates schematic part numbers
    [FDC.kicad_pcb, FDC.kicad_sch]
